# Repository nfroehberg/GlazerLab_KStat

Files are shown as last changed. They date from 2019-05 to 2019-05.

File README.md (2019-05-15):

# KStat open source potentiostat

The KStat is an adaptation with small changes to the firmware and PCB design of the open source DStat potentiostat by Michael Dryden for use with Hg/Au microelectrodes in in-situ meaurements.

Documentation for the original design: http://microfluidics.utoronto.ca/gitlab/dstat/dstat-documentation/wikis/home

For the KStat, the potential range of the potentiostat was increased from 3 to 4 (+- 2) V and the shape of the board changed from square to rectangular for easier integration in underwater housings.
As it is intended to be used in conjunction with other sensors and manipulators, the KStat uses a command-line python interface instead of the original GUI. For data analysis, a TKinter GUI was developed to display cyclic voltammograms, fit and/or remove a polynomial baseline, filter out A/C noise and measure peak heights.
Additional scripts include pH measurement and various tests used during the development.

Adaptations to firmware and PCB design by Stanley Lio.

Development of Python Interface by Nico Fröhberg.

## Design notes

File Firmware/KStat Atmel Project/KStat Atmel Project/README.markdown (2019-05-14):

This is the documentation for the DStat microcontroller firmware.

## Table of Contents:

* [Introduction](#introduction)
* [Building from source](#building-from-source)
    * [Build requirements](#build-requirements)
    * [Building with Make](#building-with-make)
* [Installation](#installation)
	* [Requirements](#requirements)
	* [Fuse bits](#fuse-bits)
	* [Firmware files](#firmware-files)
		* [Using Make](#using-make)
		* [Using avrdude directly](#using-avrdude-directly)
		* [Atmel Studio 6](#atmel-studio-6)
		* [USB DFU Flashing (experimental)](#usb-dfu-flashing-experimental)
* [Connection and testing](#connection-and-testing)
    * [Mac OS X and Linux](#mac-os-x-and-linux)
	* [Windows](#windows)
* [License](#license)

# Introduction
The DStat's operation is controlled by an Atmel XMega microcontroller.
Its main functions are to communicate instructions and data with a computer over a USB CDC interface and perform experiments by controlling the onboard peripherals.
The software that runs on the microcontroller is known as firmware and is written in plain C using many parts of Atmel's ASF framework.

# Building from source
Precompiled binaries of the firmware are [available](http://microfluidics.utoronto.ca/gitlab/dstat/dstat-firmware/builds) from the automated build system (click the download button for the desired build) and can be uploaded using [avrdude](http://www.nongnu.org/avrdude/) or Atmel Studio.
The most up to date firmware can be found in the `develop` (or individual feature) branches.

## Build requirements

* Mac or Linux:
	* GNU Make (OS X: included with Developer Tools)
	* avr-gcc (OS X: install with homebrew `brew tap osx-cross/avr && brew install avr-gcc`)
	* avr-libc (OS X: included with avr-gcc)
* Windows:
    * Docker
	
## Building with Make

The easiest way to build the firmware on Mac or Linux (Make is available in Windows, but the Makefiles may need changes to run correctly) is using the included Makefiles (from the root of dstat-firmware):
````
    make
````

This will produce the firmware binaries that will be loaded onto the microcontroller.
`atxmega256a3u_104.hex` is a bootloader for upgrading firmware over USB after the initial flash (currently experimental) and `dstat-firmware.hex` or `dstat-firmware.elf` is the actual firmware.

To compile for a dstat-hardware version earlier than 1.2.3, instead do:
````
    make BOARD_VER_MICRO=0
````

## Building with Make (using Docker)

On Windows, the easiest way to compile the source is using make from docker (Keep in mind you can use the automated build system if you don't intend to make modifications to the firmware).:

1. Install docker from https://docs.docker.com/docker-for-windows/
2. Use the tray icon for Docker to enable sharing on your C drive (under Shared Drives)
3. In a command prompt: `docker run --rm -w /src -v c:/Users/mdryden/src/dstat-firmware/DSTAT:/src --entrypoint make vyivanov/avr-docker`
   Replacing `c:/Users/mdryden/src/dstat-firmware/DSTAT` with the path to wherever you cloned the source.
   This should compile your source files and you can upload them with avrdude or Atmel Studio.

To compile for a dstat-hardware version earlier than 1.2.3, instead do:
````
    docker run --rm -w /src -v c:/Users/mdryden/src/dstat-firmware/DSTAT:/src --entrypoint "make BOARD_VER_MICRO=0" vyivanov/avr-docker
````

# Installation
## Requirements
To install the firmware onto the DStat's microcontroller, you'll need a programming tool that supports PDI.
A simple and inexpensive programmer is the [Olimex AVR ISP Mk2](https://www.olimex.com/Products/AVR/Programmers/AVR-ISP-MK2/open-source-hardware) (available from Digikey and Mouser).
In the near future, updating the firmware over USB will be supported, but a programming tool must still be used at least once to bootstrap the microcontroller.

To load the firmware, you'll need either [Atmel Studio](http://www.atmel.com/tools/atmelstudio.aspx), a full-featured development platform (Windows-only), or [AVRDUDE](http://www.nongnu.org/avrdude/), a cross-platform command line tool.
On Mac OS X, AVRDUDE can be installed using [homebrew](http://brew.sh): `brew install avrdude`

## Fuse bits
The XMega has one of the SPI ports we need configured for JTAG use, by default, and needs to be disabled by setting one of the microcontroller's fuse bits.
The JTAGEN bit of FUSEBYTE4 should be set to 1.
This only needs to be done once per microcontroller.
This must be done manually if you're using Atmel Studio, but will be taken care of automatically by the makefile method.
This can be done from the [Fuses](http://www.atmel.com/webdoc/atmelstudio/atmelstudio.programmingdialog.fuses.html) page of the Device Programming window—simply uncheck `JTAGEN` and click `Program`

## Firmware files
The memory files used to program the microcontroller are found in the root directory:
* Firmware: `dstat-firmware.elf`
* Bootloader: `atxmega256a3u_104.hex` (See note below)

Before programming, make sure your programmer is connected to your computer and its PDI connector is connected to the pin header labelled AVR-PDI on the DStat.
The side with the red wire should face the pin labelled 1 on the PCB.

### Using Make
Similar to building from source, the make command can be used to program the microcontroller using avrdude (which must be present on your system).
By default, the Makefiles are configured to use an AVR ISP mk2 connected over USB.
If you are using a different programmer, be sure to set the `AVRDUDE_PROG` and `AVRDUDE_PORT` options in the `config.mk` files found in the DSTAT and EEPROM init directories.
See `man avrdude` for more information about these options.

To upload the firmware file and set fuse bits:
````
	make program
````
The first time the fuse bits are set, verification will fail—simply run the command again.

### Using avrdude directly
The make command simply invokes avrdude.
Avrdude can be used directly if preferred (changing the -P and -c options to reflect the programmer you are using):
````
    avrdude -p x256a3u -c avrispmkII -P usb -U flash:w:atxmega256a3u_104.hex:i -U application:w:dstat-firmware.elf:e -U fuse4:w:0xff:m -U fuse2:w:0xbf:m
````

### Atmel Studio 6
Follow the directions [here](http://www.atmel.com/webdoc/atmelstudio/atmelstudio.AVRStudio.ProgrammingDialog.Introduction.html) to program the microcontroller.
Be sure to select `ATXMEGA256A3U` as the Device and `PDI` as Interface.

In the Memories tab, `dstat-firmware.elf` should be selected for Flash

### USB DFU Flashing (experimental)
Version 1.2.3 PCBs are equipped with a switch that can be used to put the DStat into a USB flashing mode.
If the switch (SW1) is depressed while plugging the USB cable in, the DStat should boot to the DFU firmware (if done correctly, no LEDs should be lit on the board).
In this mode, the firmware can be updated over USB using Atmel FLIP or avrdude.

Using make:
````
    make dfu
````

Using avrdude directly:
````
    avrdude -p x256a3u -c flip2 -U application:w:dstat-firmware.elf:e
````

To boot back into the normal DStat firmware, replug the USB without the switch depressed.

Note, DFU flashing will only work if the DFU bootloader is installed and can't be used to set flash bits or flash a new bootloader.
Unfortunately the XMega doesn't come with a bootloader installed, so flashing with a PDI programmer must be done for at least the first time.

# Connection and testing
If the firmware has been successfully applied, it will be possible to connect to the DStat over USB.

## Mac OS X and Linux
Mac OS X and Linux do not require driver files and will automatically enumerate the DStat and give it an entry in /dev/ as a virtual serial port.
On OS X, the DStat should appear as `cu.usbmodem12...E1`.
On Linux, check the /dev/ directory for new entries after you plug the DStat in.

Once connected, you can test communications using a terminal emulator (following the communications protocol in `dstat-firmware/communication protocol.txt`):
````
    $ screen /dev/cu.usbmodem12...E1
    $ c
    #
    $ k
    #INFO: 30k
````
## Windows
*It seems that Windows 10 no longer requires the steps below and will automagically install a suitable driver.*

Unlike Mac and Linux, Windows does not automatically load its USB CDC driver and needs a wrapper driver installed.
The process is similar to installing [Arduino drivers](http://www.arduino.cc/en/guide/windows#toc4), but using the driver file included in the `drivers` directory of `dstat-interface`.
Unfortunately, if you are running Windows 8 or above, this requires disabling driver signing enforcement (thank Microsoft), but actually installing Arduino should install suitable drivers.

# License
ASF code is subject to the following copyright terms:
````
	*Copyright (c) 2012 Atmel Corporation. All rights reserved.
	*
	* Redistribution and use in source and binary forms, with or without
	* modification, are permitted provided that the following conditions are met:
	*
	* 1. Redistributions of source code must retain the above copyright notice,
	*    this list of conditions and the following disclaimer.
	*
	* 2. Redistributions in binary form must reproduce the above copyright notice,
	*    this list of conditions and the following disclaimer in the documentation
	*    and/or other materials provided with the distribution.
	*
	* 3. The name of Atmel may not be used to endorse or promote products derived
	*    from this software without specific prior written permission.
	*
	* 4. This software may only be redistributed and used in connection with an
	*    Atmel microcontroller product.
	*
	* THIS SOFTWARE IS PROVIDED BY ATMEL "AS IS" AND ANY EXPRESS OR IMPLIED
	* WARRANTIES, INCLUDING, BUT NOT LIMITED TO, THE IMPLIED WARRANTIES OF
	* MERCHANTABILITY, FITNESS FOR A PARTICULAR PURPOSE AND NON-INFRINGEMENT ARE
	* EXPRESSLY AND SPECIFICALLY DISCLAIMED. IN NO EVENT SHALL ATMEL BE LIABLE FOR
	* ANY DIRECT, INDIRECT, INCIDENTAL, SPECIAL, EXEMPLARY, OR CONSEQUENTIAL
	* DAMAGES (INCLUDING, BUT NOT LIMITED TO, PROCUREMENT OF SUBSTITUTE GOODS
	* OR SERVICES; LOSS OF USE, DATA, OR PROFITS; OR BUSINESS INTERRUPTION)
	* HOWEVER CAUSED AND ON ANY THEORY OF LIABILITY, WHETHER IN CONTRACT,
	* STRICT LIABILITY, OR TORT (INCLUDING NEGLIGENCE OR OTHERWISE) ARISING IN
	* ANY WAY OUT OF THE USE OF THIS SOFTWARE, EVEN IF ADVISED OF THE
	* POSSIBILITY OF SUCH DAMAGE.
````
All other code is licensed under the [GNU Public License](/LICENSE) v3.

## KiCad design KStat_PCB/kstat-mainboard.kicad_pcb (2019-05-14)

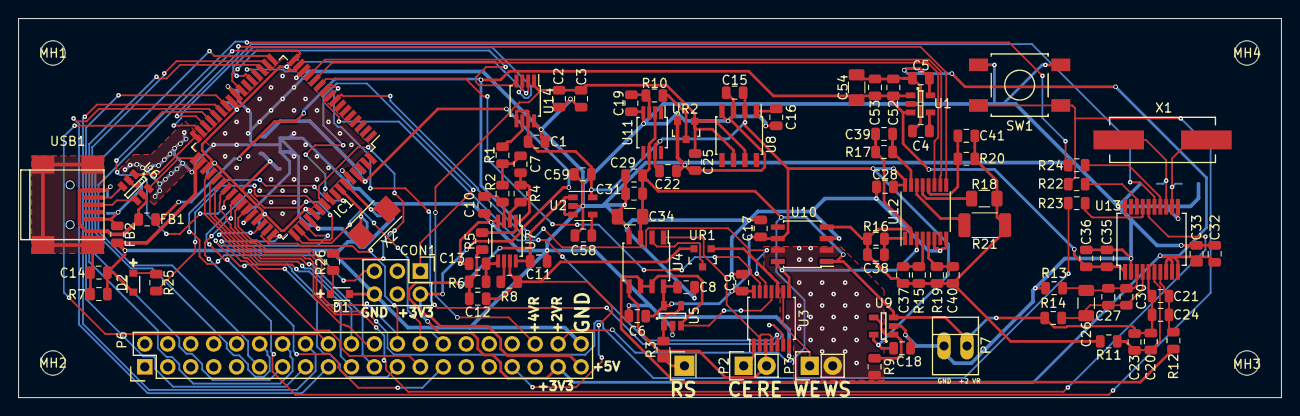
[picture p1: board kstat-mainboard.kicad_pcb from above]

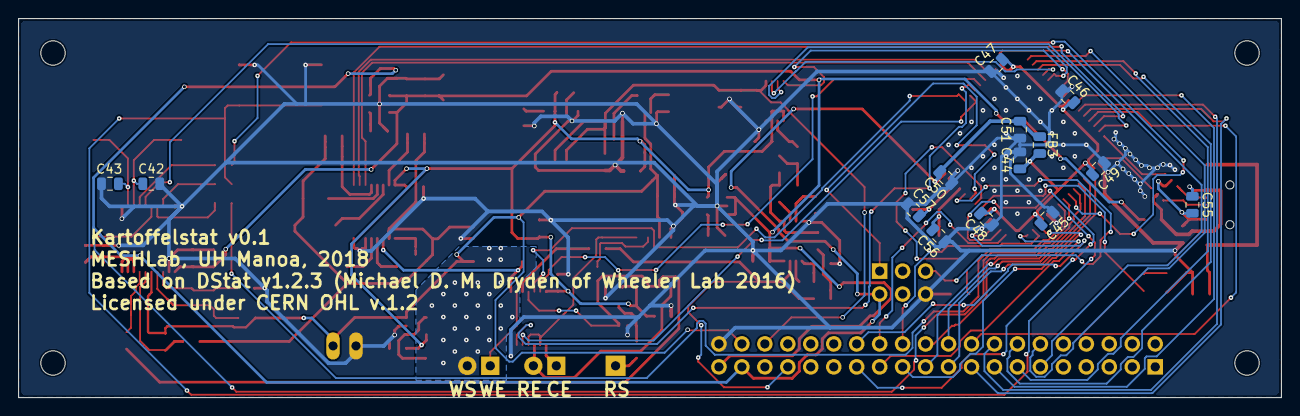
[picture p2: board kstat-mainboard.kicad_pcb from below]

Board: 2 copper layers, 139.7 x 41.9 mm, 121 parts (14 on the bottom side), 98 nets.

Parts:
C1, C2, C6, C8, C11, C16, C17, C18, C20, C21, C22, C27, C28, C29, C33, C35, C45, C46, C47, C48, C49, C50, C52: 100n; C_0805_2012Metric
C3, C19, C25, C31, C53: 1u; C_0805_2012Metric
C4, C9, C55, C58: 10n; C_0805_2012Metric
C5, C32, C36, C44, C51, C59: 10u; C_0805_2012Metric
C7, C12: 180p; C_0805_2012Metric
C10: 160p; C_0805_2012Metric
C13: 68p; C_0805_2012Metric
C14, C15: 4.7n; C_0805_2012Metric
C23, C24, C30: 100p; C_0805_2012Metric
C26, C34, C54: 47u; C_1206_3216Metric
C37: 56n; C_0805_2012Metric
C38: 200p; C_0805_2012Metric
C39: 2p; C_0805_2012Metric
C40: 2n; C_0805_2012Metric
C41: 20p; C_0805_2012Metric
C42, C43: 18p; C_0805_2012Metric
C56, C57: 15p; C_0805_2012Metric
CON1: AVR-PDI; Pin_Header_Straight_2x03
D1, D2: LED; D_0805
FB1, FB2: FILTER; C_0805_2012Metric
FB3: FERRITE; C_0805_2012Metric
IC1: ATXMEGA256A3U; TQFP-64_14x14mm_P0.8mm
MH1, MH2, MH3, MH4: MountingHole; MountingHole_2.7mm_M2.5
P1: RS; Pin_Header_Straight_1x01
P2: C R; Pin_Header_Straight_1x02
P3: W WS; Pin_Header_Straight_1x02
P6: CONN_01X40; Pin_Header_Straight_2x20
P7: CONN_2; PINHEAD1-2
R1, R2: 18.7k; R_0805_2012Metric
R3, R9, R15, R22, R23, R24: 100; R_0805_2012Metric
R4, R8: 1k; R_0805_2012Metric
R5, R6: 25.5k; R_0805_2012Metric
R7: 1M; R_0805_2012Metric
R10: 10k; R_0805_2012Metric
R11, R12: 301; R_0805_2012Metric
R13, R14: 49.9; R_0805_2012Metric
R16: 30k; R_0805_2012Metric
R17: 3M; R_0805_2012Metric
R18: 100M; R_1206_3216Metric
R19: 3k; R_0805_2012Metric
R20: 300k; R_0805_2012Metric
R21: 30M; R_2010_5025Metric
R25, R26: 330; R_0805_2012Metric
SW1: RESET; SW_SPST_SMD
U1: TPS79933; SOT-23-5
U2: TPS793475-EP; SOT-23-5
U3: MAX4737; TSSOP-14_4.4x5mm_Pitch0.65mm
U4: LMP7702; SOIC-8_3.9x4.9mm_Pitch1.27mm
U5, U9: LMP7715MF; SOT-23-5
U6: TPD2S017; SOT-23-6
U7: MAX4477; MSOP-8_3x3mm_Pitch0.65mm
U8: MAX6126; SOIC-8_3.9x4.9mm_Pitch1.27mm
U10: LMP7721; SOIC-8_3.9x4.9mm_Pitch1.27mm
U11: OPA350; MSOP-8_3x3mm_Pitch0.65mm
U12: MAX4617; TSSOP-16_4.4x5mm_Pitch0.65mm
U13: ADS1255; SSOP-20_5.3x7.2mm_Pitch0.65mm
U14: MAX5441; MSOP-8_3x3mm_P0.65mm
UR1, UR2: MAX5491; SOT-23
USB1: USB-MB-S; USB_Mini-B
X1: 7.68M; Crystal_HC49-SD_SMD
X2: 12 MHz; Crystal_SMD_5032_2Pads

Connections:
+2VR: C20.1, C21.1, C23.1, C24.1, C29.1, C31.1, C34.1, P6.38, P7.2, R14.1, U4.3, U9.3, U10.1, U11.2, U11.6, U13.5
+3V3: C5.2, C32.2, C33.2, C50.2, C51.2, CON1.2, FB3.2, IC1.61, P6.37, U1.5, U13.8, U13.9, U13.10
+4.75VR: C1.1, C6.1, C8.1, C9.2, C15.1, C17.2, C18.1, C22.1, C28.2, C59.1, U2.5, U3.14, U4.8, U5.5, U8.2, U9.5, U10.6, U11.7, U12.16, U14.5, U14.7
+4VR: C2.1, C3.1, C25.1, P6.36, U8.6, U8.7, U14.1, UR2.1
+5V: C11.1, C35.1, C36.1, C52.1, C53.1, C54.1, FB1.1, P6.39, U1.1, U1.3, U2.1, U2.3, U7.8, U13.1
/ADC: C37.2, C38.2, C39.2, C40.2, C41.2, R11.1, R15.2, R16.2, R17.2, R18.2, R19.2, R20.2, R21.2, U10.4, U12.2
/COUNTER: P2.1, U3.1
/DAC_OUT: C12.2, P6.33, R8.1, U7.7, UR1.2
/DM: IC1.32, U6.1
/DP: IC1.33, U6.6
/PB2: IC1.8, U3.12
/PB3: IC1.9, U3.5
/PB4: IC1.10, U3.6
/PB5: IC1.11, U3.13
/PB6: IC1.12, U12.11
/PB7: IC1.13, U12.10
/PC0: IC1.16, P6.11
/PC1: IC1.17, P6.12
/PC2: IC1.18, P6.13
/PC3: IC1.19, P6.14
/PC4: IC1.20, U14.2
/PC5: IC1.21, U14.3
/PC7: IC1.23, U14.4
/PD0: IC1.26, P6.15
/PD1: IC1.27, P6.16
/PD2: IC1.28, P6.17
/PD3: IC1.29, P6.18
/PD4: IC1.30, U12.9
/PD5: IC1.31, U13.15
/PDI_CLK: CON1.5, IC1.57
/PDI_DATA: CON1.1, IC1.56
/PE0: IC1.36, P6.19
/PE1: IC1.37, P6.20
/PE2: IC1.38, P6.21
/PE3: IC1.39, P6.22
/PE4: IC1.40, R24.2
/PE5: IC1.41, R22.2, SW1.1
/PE6: IC1.42, U13.16
/PE7: IC1.43, R23.2
/PF0: IC1.46, P6.23
/PF1: IC1.47, P6.24
/PF2: IC1.48, P6.25
/PF3: IC1.49, P6.26
/PF4: IC1.50, P6.27
/PF5: IC1.51, P6.28
/PF6: IC1.54, R25.1
/PF7: IC1.55, R26.1
/REFERENCE: P2.2, U3.3, U4.5
/REF_V: R12.1, U3.11, U4.6, U4.7, U5.3
/RSHIELD: P1.1, R3.2
/USB_GND: C55.2, FB2.2, U6.2, USB1.5
/USB_VCC: C55.1, FB1.2, U6.5, USB1.1
/WORKING: P3.1, U3.9
/WSHIELD: P3.2, R9.2, U10.2, U10.7
GND: C1.2, C2.2, C3.2, C4.2, C5.1, C6.2, C8.2, C9.1, C10.1, C11.2, C13.1, C14.2, C15.2, C16.2, C17.1, C18.2, C19.2, C22.2, C25.2, C28.1, C29.2, C31.2, C32.1, C33.1, C34.2, C35.2, C36.2, C42.2, C43.2, C44.1, C45.1, C46.1, C47.1, C48.1, C49.1, C50.1, C51.1, C52.2, C53.2, C54.2, C56.1, C57.1, C58.2, C59.2, CON1.6, D1.1, D2.1, FB2.1, IC1.14, IC1.24, IC1.34, IC1.44, IC1.52, IC1.60, P6.40, P7.1, R7.2, R13.1, SW1.2, U1.2, U2.2, U3.7, U4.4, U5.2, U7.4, U8.3, U8.4, U9.2, U10.3, U11.4, U12.6, U12.8, U13.2, U13.11, U13.20, U14.8, UR2.2
unnamed: C4.1, U1.4
unnamed: C7.1, R1.2, R2.1
unnamed: C7.2, R4.1, R5.1, U7.1
unnamed: C10.2, R2.2, U7.3
unnamed: C12.1, R5.2, R6.1
unnamed: C13.2, R6.2, U7.5
unnamed: C14.1, R7.1, USB1.6
unnamed: C16.1, U8.1
unnamed: C19.1, R10.2, U11.3
unnamed: C20.2, C23.2, R11.2, U13.6
unnamed: C21.2, C24.2, R12.2, U13.7
unnamed: C26.1, C27.1, C30.1, R13.2, U13.3
unnamed: C26.2, C27.2, C30.2, R14.2, U13.4
unnamed: C37.1, R15.1, U12.4
unnamed: C38.1, R16.1, U12.1
unnamed: C39.1, R17.1, U12.15
unnamed: C40.1, R19.1, U12.5
unnamed: C41.1, R20.1, U12.12
unnamed: C42.1, U13.13, X1.2
unnamed: C43.1, U13.12, X1.1
unnamed: C44.2, C45.2, C46.2, C47.2, C48.2, C49.2, FB3.1, IC1.15, IC1.25, IC1.35, IC1.45, IC1.53
unnamed: C56.2, IC1.58, X2.2
unnamed: C57.2, IC1.59, X2.1
unnamed: C58.1, U2.4
unnamed: D1.2, R26.2
unnamed: D2.2, R25.2
unnamed: R1.1, U14.6
unnamed: R3.1, U5.1, U5.4
unnamed: R4.2, U7.2
unnamed: R8.2, U7.6
unnamed: R9.1, U9.1, U9.4
unnamed: R10.1, UR2.3
unnamed: R18.1, U12.13
unnamed: R21.1, U12.14
unnamed: R22.1, U13.18
unnamed: R23.1, U13.17
unnamed: R24.1, U13.14
unnamed: U3.2, U3.4, U4.1
unnamed: U3.10, UR1.1
unnamed: U4.2, UR1.3
unnamed: U6.3, USB1.2
unnamed: U6.4, USB1.3
unnamed: U3.8, U10.8, U12.3

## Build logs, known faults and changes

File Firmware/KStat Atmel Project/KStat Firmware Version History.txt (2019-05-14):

20181108: 	default
20181109: 	added end of scan and end of experiment signal to linear sweep method
20181109b: 	Changed idle method to take numeric input (idle_volts as uint16 DAC index) and set the idle voltage to that.
		also changed it from having only switches to CE and 2 Electrode (PB3 and PB5) to also working and control (PB2 and PB4)

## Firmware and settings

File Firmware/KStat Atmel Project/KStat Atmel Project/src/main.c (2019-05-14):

/*
 * main.c
 *
 * Created: 29/09/2012 2:13:52 AM
 *  Author: mdryden
 */ 

#include "experiment.h"
#include "asf.h"
#include "settings.h"
#include "tcs.h"
#include "shutter.h"
#include <string.h>
#include <math.h>
#include <stdint.h>
#include "conf_board.h"
#include "ext_twi.h"
#include "usb.h"
#include <util/atomic.h>

//Internal function declarations
static void command_handler(uint16_t bytes);

static void command_handler(uint16_t bytes){
	/**
	 * Deals with commands over USB
	 *
	 * Calls functions in 
	 * @param command Command character input.
     * @param bytes Number of command bytes to wait for
	 */
    
    if (bytes == 0) {
        printf("@RCV 0\n");
        return;
    }
    else if (bytes >= MAX_COMMAND_BYTES){
        printf("@ERR Command too long\n");
        return;
    }
    
    char command_buffer[MAX_COMMAND_BYTES];
    
read_data:
    while (!udi_cdc_is_rx_ready());
    delay_ms(100);
    if(!fgets(command_buffer, MAX_COMMAND_BYTES, stdin)){
        printf("@ERR Could not read string\n");
        return;
    }
    
    command_buffer[strcspn(command_buffer, "\r\n")] = 0;
    
    if (strlen(command_buffer) == 0)
        goto read_data;
    
    printf("@RCV %u\n", strlen(command_buffer));
    printf("#%s\n", command_buffer);
    
    char command = command_buffer[0];
    
	switch (command){
        case 'E': //Experiment options
            experiment_handler(command_buffer+1);
            break;
        
        case 'S': //Settings options
            settings_handler(command_buffer+1);
            break;
            
        case 'T': ;
            uint16_t tcs_data[] = {0,0,0,0};
            if (settings.settings.tcs_enabled == 0){
                printf("T-1.-1.-1.-1\n");
            }
            else{
                tcs_readvalues(tcs_data);
                printf("#INFO: TCS—%u %u %u %u\n", tcs_data[0], tcs_data[1], tcs_data[2], tcs_data[3]);
                printf("T%u.%u.%u.%u\n", tcs_data[0], tcs_data[1], tcs_data[2], tcs_data[3]);
            }
            break;
        
        case 'R': //Restart USB
            udc_detach();
            delay_ms(100);
            udc_attach();
            break;
            
		case 'V': //check version
            #define STRING2(x) #x
            #define STRING(x) STRING2(x)
            printf("V%u.%u.%u-%lu\n", BOARD_VER_MAJOR, BOARD_VER_MINOR, BOARD_VER_MICRO);
			break;
		
		default:
			printf("@ERR Command %c not recognized\n", command);
			return;
	}
	printf("@DONE\n");
	return;
}

int main(void){
    irq_initialize_vectors();
    cpu_irq_enable();
    
	board_init();
    #if BOARD_VER_MAJOR >= 1 && BOARD_VER_MINOR >= 2 && BOARD_VER_MICRO >=3
        ioport_set_pin_dir(LED1, IOPORT_DIR_OUTPUT);
        ioport_set_pin_dir(LED2, IOPORT_DIR_OUTPUT);
    #endif
	pot_init();
	pmic_init();
	
	sysclk_init(); //Disables ALL peripheral clocks D:

	rtc_init();
    sleepmgr_init();
	sysclk_enable_module(SYSCLK_PORT_GEN, SYSCLK_EVSYS);
	
	pmic_set_scheduling(PMIC_SCH_ROUND_ROBIN);
    
    init_build_usb_serial_number();
    
	stdio_usb_init();
	
	ads1255_init_pins();
	ads1255_init_module();

	PORTD.INT0MASK = PIN5_bm;
	PORTD.INT1MASK = PIN5_bm;
	PORTD.INTCTRL = PORT_INT0LVL_OFF_gc | PORT_INT1LVL_OFF_gc;
	
	max5443_init_pins();
	max5443_init_module();
	
	ads1255_wakeup();
	ads1255_rdatac();
	ads1255_standby();
    
    ads1255_setup(ADS_BUFF_ON,ADS_DR_60,ADS_PGA_2);
    
    autogain_enable = 0;
    g_gain = POT_GAIN_30k;
    pot_set_gain();
    
    settings_read_eeprom();

    ext_twi_init();
    
    tcs_init();
    shutter_init();
	
    delay_s(1);
    udc_detach();
    delay_ms(100);
    udc_attach();
    stdio_usb_enable();
    
    uint16_t bytes_sent = 0;
    
	program_loop:
        #if BOARD_VER_MAJOR >= 1 && BOARD_VER_MINOR >= 2 && BOARD_VER_MICRO >=3
            ioport_set_pin_level(LED1, 1);
        #endif
		while (getchar() != '!');
        scanf("%u", &bytes_sent);
    
    
//        // Empty buffer
//        while (udi_cdc_is_rx_ready())
//            udi_cdc_getc();
    
		printf ("@ACK %u\n", bytes_sent);
        #if BOARD_VER_MAJOR >= 1 && BOARD_VER_MINOR >= 2 && BOARD_VER_MICRO >=3
            ioport_set_pin_level(LED1, 0);
        #endif
    
		command_handler(bytes_sent);
	goto program_loop;
}

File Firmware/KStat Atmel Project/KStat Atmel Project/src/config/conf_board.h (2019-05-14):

/**
 * \file
 *
 * \brief User board configuration template
 *
 */

#ifndef CONF_BOARD_H
#define CONF_BOARD_H

#include <ioport.h>

#if BOARD_VER_MAJOR >= 1 && BOARD_VER_MINOR >= 2 && BOARD_VER_MICRO >=3
    #define BOARD_XOSC_HZ          12000000
    #define BOARD_XOSC_TYPE        XOSC_TYPE_XTAL
    #define BOARD_XOSC_STARTUP_US  1000

    #define LED1    IOPORT_CREATE_PIN(PORTF,7)
    #define LED2    IOPORT_CREATE_PIN(PORTF,6)
#endif

#define MAX_COMMAND_BYTES   64

// Default Settings (only used if EEPROM is empty)
#define SETTINGS_MAX5443_OFFSET 0
#define SETTINGS_TCS_ENABLED 1
#define SETTINGS_TCS_CLEAR_THRESHOLD 10000U
#define SETTINGS_R100_TRIM 0
#define SETTINGS_R3k_TRIM 0
#define SETTINGS_R30k_TRIM 0
#define SETTINGS_R300k_TRIM 0
#define SETTINGS_R3M_TRIM 0
#define SETTINGS_R30M_TRIM 0
#define SETTINGS_R100M_TRIM 0
#define SETTINGS_EIS_CAL1 3000U
#define SETTINGS_EIS_CAL2 3000000UL
#define SETTINGS_DAC_UNITS_TRUE 0


#endif // CONF_BOARD_H

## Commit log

2019-05-14 Initializing Git Repository
    [kstat-mainboard-B.Cu.gbl, kstat-mainboard-B.Mask.gbs, kstat-mainboard-B.Paste.gbp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]
2019-05-15 adding scripts for in-situ and sediment work
    [KStat_cyclic_params.txt]

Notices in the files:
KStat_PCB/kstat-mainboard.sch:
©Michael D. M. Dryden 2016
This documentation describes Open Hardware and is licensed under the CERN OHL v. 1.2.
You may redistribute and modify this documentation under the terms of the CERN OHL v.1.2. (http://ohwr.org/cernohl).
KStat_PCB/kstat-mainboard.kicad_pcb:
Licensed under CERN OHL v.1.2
